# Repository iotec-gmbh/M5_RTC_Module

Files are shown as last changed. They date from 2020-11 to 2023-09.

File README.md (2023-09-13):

# M5-RTC-Module

The M5-RTC-Mod is a real time clock specifically designed for the popular ESP32 based [M5-Stack](https://m5stack.com/). It features the [RV-3028-C7 RTC from Micro Crystal](https://www.microcrystal.com/en/products/real-time-clock-rtc-modules/rv-3028-c7).

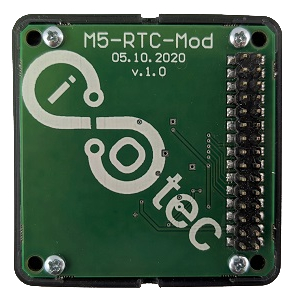
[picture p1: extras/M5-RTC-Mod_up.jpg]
M5-RTC-Module upside

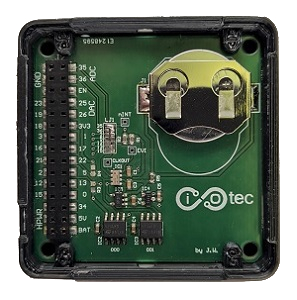
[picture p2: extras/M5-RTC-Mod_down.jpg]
M5-RTC-Module downside


## Features

+ **high precision** [RTC](https://www.microcrystal.com/en/products/real-time-clock-rtc-modules/rv-3028-c7) with ±1ppm deviation per year (±32 seconds per year)
+ extremely **long battery runtime** with a CR2032 lithium cell (at least 10 Years, considering the operating life of the battery)
+ fully compatible to the [M5Stack Core](https://m5stack.com/collections/m5-core)
+ two external [EEPROMs](https://www.st.com/en/memories/m24256-bw.html)
+ battery voltage monitoring through a 10-bit [ADC](http://ww1.microchip.com/downloads/en/DeviceDoc/20001805C.pdf).
+ configurable interrupt pin
+ 3D printable housing for an M5Stack
+ all components are connected via a single I2C bus

## Repository Contents

+ **/examples** – example sketches for the library
+ **/src** – source files for the library (`.cpp`, `.h`)
+ **/extras/hardware** – schematic, Gerber-files and bill of material
+ **/extras/3D-files** – `.stl`-file for 3D printing

## Dependencies

The library is based on the [RTC RV-3028-C7 Arduino Library](https://github.com/constiko/RV-3028_C7-Arduino_Library).
It also includes the [uEEPROMLib](https://github.com/Naguissa/uEEPROMLib) for communication with the external EEPROM via I2C.
The battery voltage is monitored using the [MCP3X21](https://github.com/pilotak/MCP3X21) library.

## API

The following functions are included in this library:

+ `begin()` – initializes the I2C-Interface and the RTC. Must be called in the setup function
+ `setLocalTimeToRTC()` – set the time on the ESP32 to the M5-RTC-Mod
+ `getBatteryStatus()` – returns true if the battery is ok, false if it's to low
+ `getBatteryVoltage()` – returns the battery Voltage in mV

This library works best in combination with functions from the included libraries:

+ Additional functions to control the **RTC** are described [here](https://github.com/constiko/RV-3028_C7-Arduino_Library#general-functions). You can use these by adding `.rtc` to the call of the function.
+ Additional functions to control the **EEPROM** are described [here](https://naguissa.github.io/uEEPROMLib_doc_and_extras/classuEEPROMLib.html). You can use these by adding `.eeprom0` or `.eeprom1` to the call of the function.
+ Additional functions to control the **ADC** are described [here](https://github.com/pilotak/MCP3X21). You can use these by adding `.adc` to the call of the function.

## Usage

Here is an example on how to use the library:

```cpp
#include <M5_RTC_Module.h>

// create an instance of the class M5_RTC_Mod
M5_RTC_Mod rtc_mod;

void setup(){
    // init RTC-Module
    rtc_mod.begin()
}

void loop(){
    // Updates the time variables from RTC
    if (rtc_mod.rtc.updateTime()) {
        currentTime = rtc_mod.rtc.stringTimeStamp();
    } else {
        // RTC failed to update
    }
}

```

### Choosing the interrupt pin

You can [set up an interrupt event](https://github.com/constiko/RV-3028_C7-Arduino_Library#alarm-interrupt-functions) on the RTC.
With the help of the solder jumper LJ1 on the M5-RTC-Mod board you can choose which IO of the ESP32 should act as an interrupt pin.

The following IOs can be chosen as an interrupt pin:

|  |  | | |  |  |  |
|--|--|-|-|--|--|--|
|35|36|2|5|12|13|15|

For example: In the following picture the IO 35 is used as an interrupt pin.

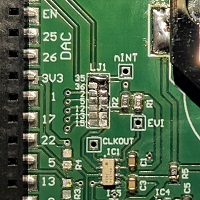
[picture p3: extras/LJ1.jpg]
LJ1


## Contribute

We look forward to contributions, reports or comments on the hardware or software.

If you have any question feel free to contact us: info@iotec-gmbh.de

## License

See [LICENSE](LICENSE) file for more information.

Copyright (c) 2020 iotec GmbH

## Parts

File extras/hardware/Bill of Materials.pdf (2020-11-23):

v.1.0 | 20.11.2020
Quantity | Comment | Designator | PartMandatory | Footprint | Description | Manufacturer | Manufacturer number
2 | 10n | C1, C3 | Yes | CAP0603_M | 10nF, at least 6.3V SMD ceramic capacitor, 0603 package | - | -
3 | 100n | C2, C4, C5 | Yes | CAP0603_M | 100nF, at least 6.3V SMD ceramic capacitor, 0603 package | - | -
1 | 1u | C6 | Yes | CAP0603_M | 1µF, at least 6.3V SMD ceramic capacitor, 0603 package | - | -
1 | RV-3028-C7 | IC1 | Yes | RV-3028-C7 | Real-Time Clock Module | Micro Chrystal | RV-3028-C7 32.768kHz 1ppm TA QC
2 | M24256 | IC2, IC3 | No | SO8N | 256-Kbit I2C-compatible EEPROM | STMicroelectronics | M24256-DFMN6TP
1 | MCP1525/41 | IC4 | No | SOT23_3L_M | 4.096V precision voltage reference | Microchip | MCP1541T-I/TT
1 | MCP3021 | IC5 | No | SOT23_5L_M | 10-bit ADC | Microchip | MCP3021A0T-E/OT
1 | CR2032-Bat-Holder | J1 | Yes | CR2032-BAT-HOLDER | SMD battery holder for CR2032 coin cell | Linx | BAT-HL-001
1 | Pin Header for the M5-Stack | J2 | Yes | 2x15 Pin Header low profile | BUS-Socket is a pair of M-BUS socket, female and male. 2X15 pins. | M5Stack | A001
4 | 10k | R1, R2, R3, R4 | Yes | RES0603_M | 10kΩ chip resistor, 0603 package | - | -
1 | 470 | R5 | Yes | RES0603_M | 470Ω chip resistor, 0603 package | - | -

Copyright (c) 2020 iotec GmbH

Bill of Material M5-RTC-Module

MIT License: Provided "as is", without warranty of any kind.

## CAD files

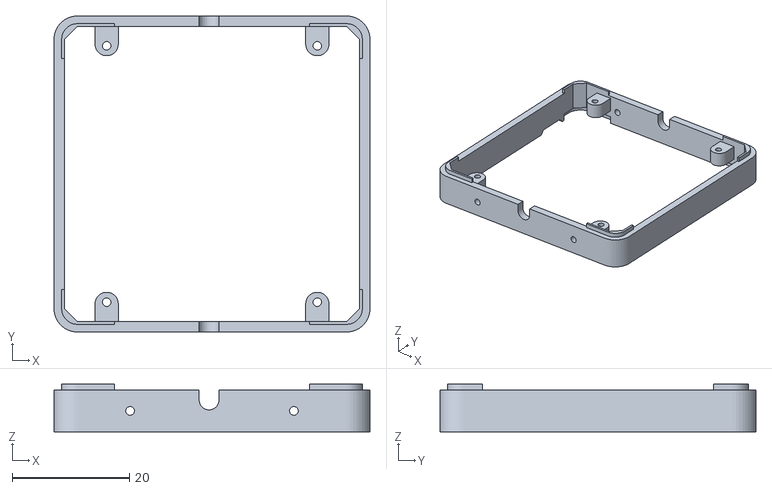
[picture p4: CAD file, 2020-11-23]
extras/3D-files/M5_RTC_Mod_Case.stl
54.0 x 54.0 x 8.15

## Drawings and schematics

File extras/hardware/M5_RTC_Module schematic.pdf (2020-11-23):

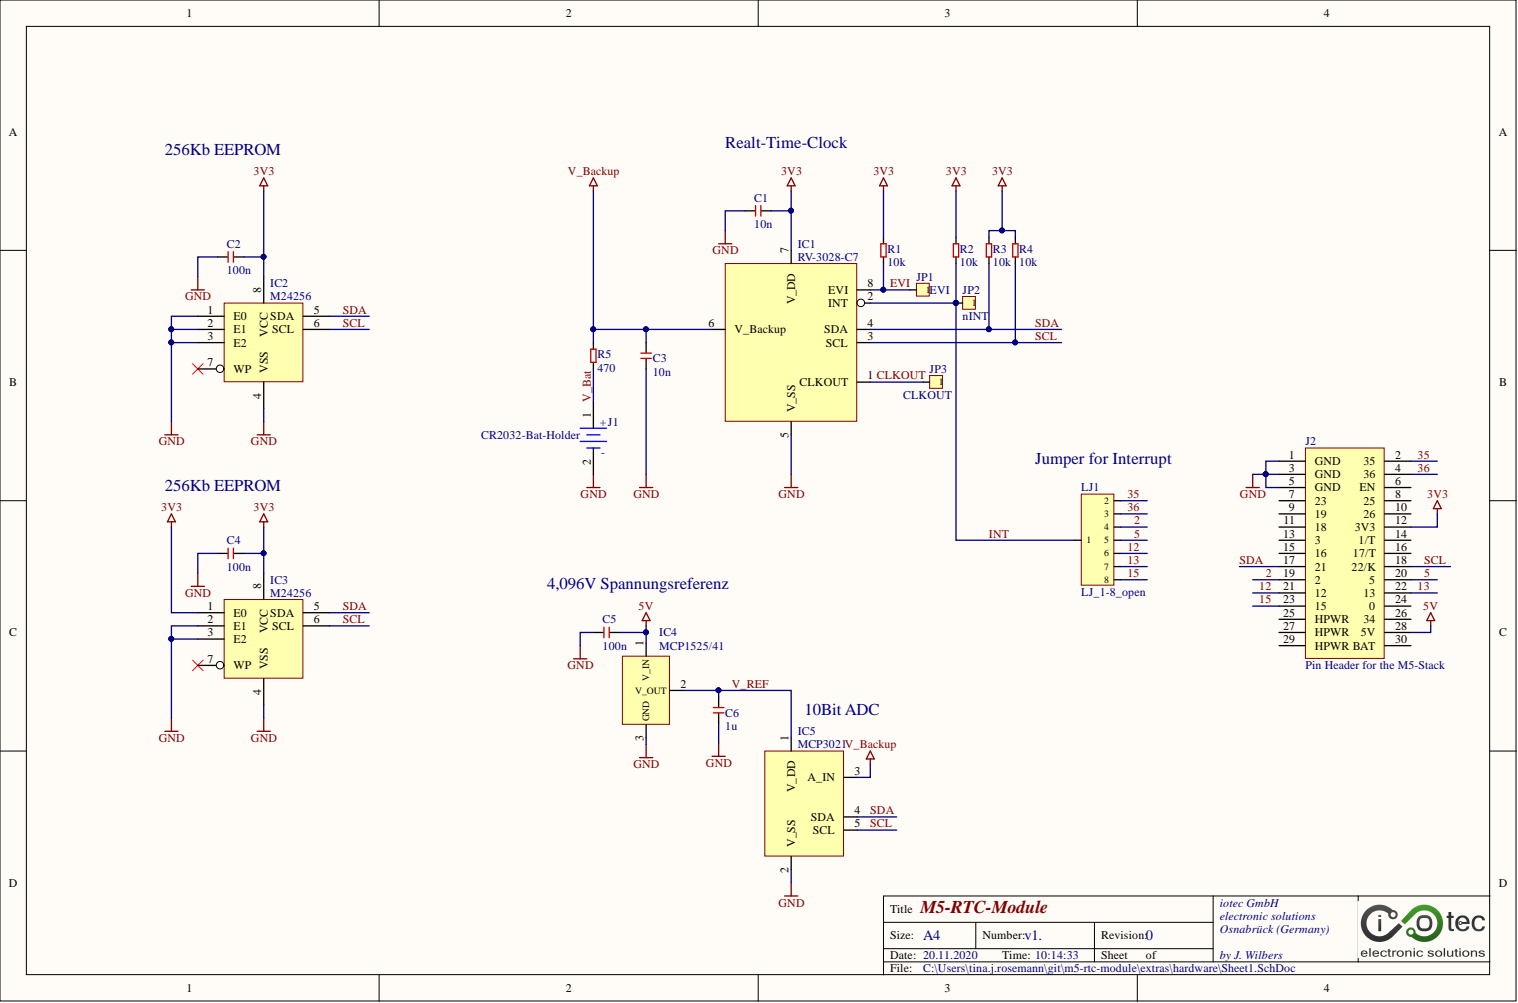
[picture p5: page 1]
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

Size: A 4 | N umber: | Rev i s i o n : 0
Date: 2 0.1 1.2 0 2 0 T ime: 1 0 : 1 4 : 3 3 | | Sheet o f

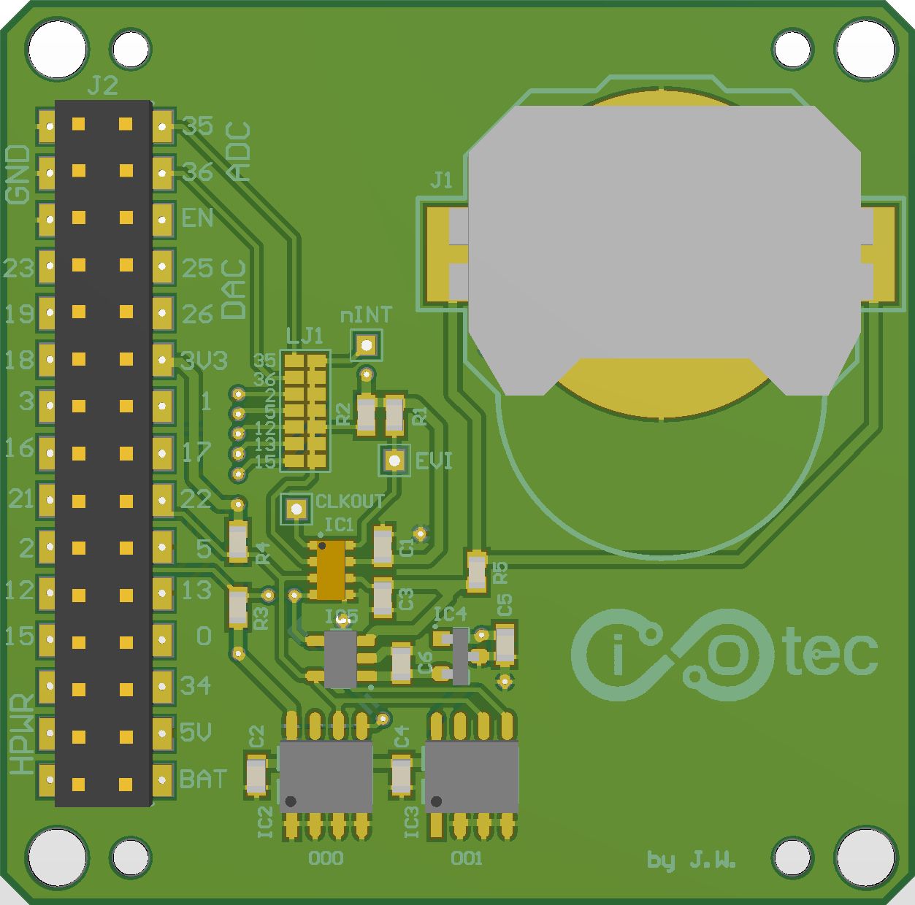
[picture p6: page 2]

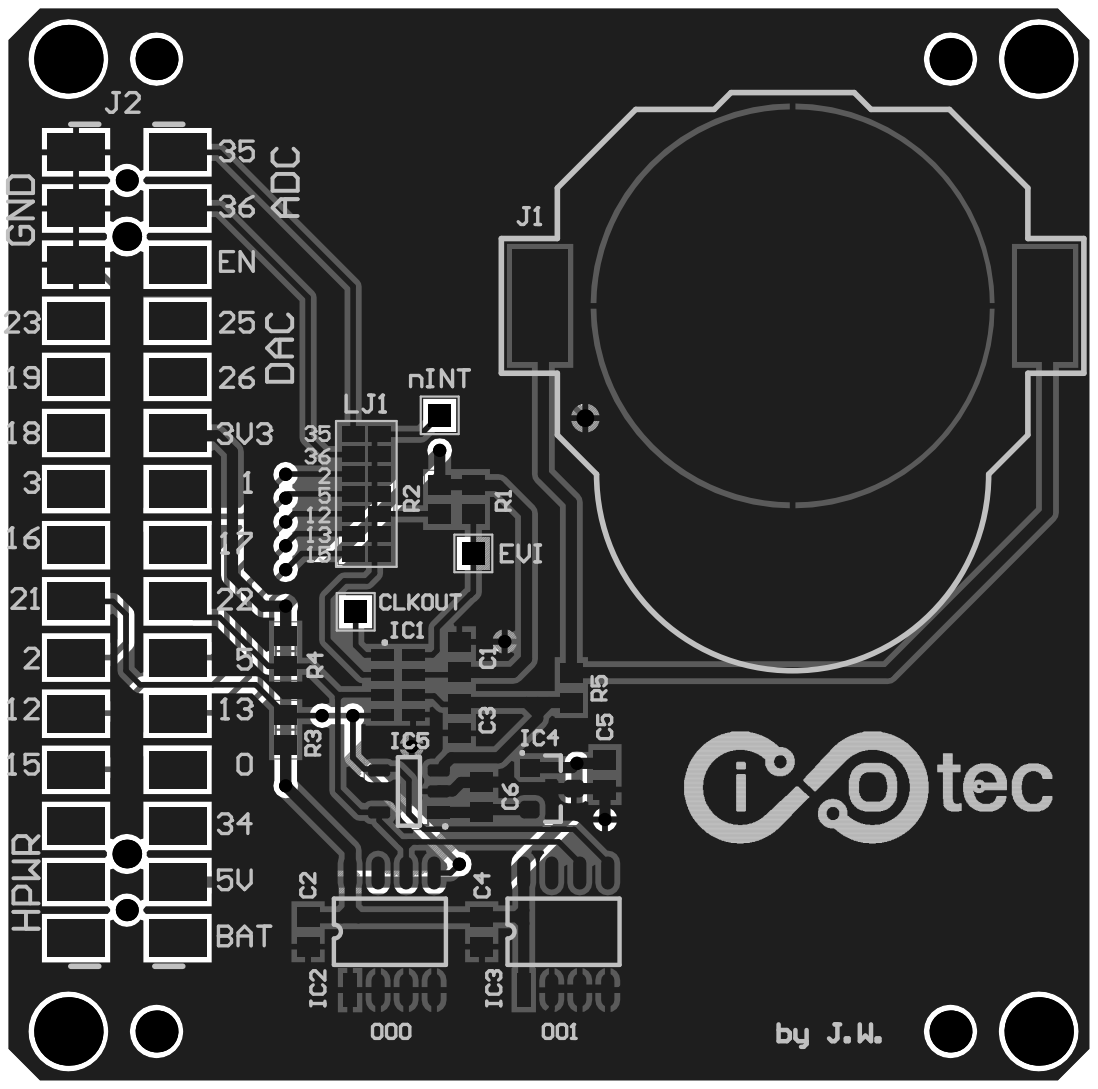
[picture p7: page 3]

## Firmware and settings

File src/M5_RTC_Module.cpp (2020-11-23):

/*
 * @file M5_RTC_Module.cpp
 * @brief Library for using the RTC-Module from iotec for the M5-Stack
 * @author Created by Johannes W.
 * @date November 12, 2020.
 * @copyright Copyright (c) 2020 iotec GmbH
 */

#include <Arduino.h>
#include <M5_RTC_Module.h>

M5_RTC_Mod::M5_RTC_Mod(uint8_t adrEeprom0, uint8_t adrEeprom1, uint8_t adrAdc)
    : eeprom0(adrEeprom0),
      eeprom1(adrEeprom1),
      rtc(),
      adc(adrAdc) {
}

bool M5_RTC_Mod::begin(TwoWire &wirePort, bool set24Hour, bool disableTrickleCharge, bool setLevelSwitchingMode) {
    // initialize I2C communication
    wirePort.begin();

    // initialize adc
    adc.init(&wirePort);

    // initialize real time clock
    if (rtc.begin(wirePort, set24Hour, disableTrickleCharge, setLevelSwitchingMode)) {
        return true;
    } else {
        return false;
    }

    // set all values in the rtc to default and clear all flags
    rtc.clearInterrupts();
    rtc.disableAlarmInterrupt();
    rtc.clearAlarmInterruptFlag();
    rtc.disableTimer();
    rtc.disableTimerInterrupt();
    rtc.clearTimerInterruptFlag();
    rtc.disablePeriodicUpdateInterrupt();
    rtc.clearPeriodicUpdateInterruptFlag();
    rtc.disableClockOut();
    rtc.clearClockOutputInterruptFlag();
    rtc.reset();

    // write system time to RTC
    setLocalTimeToRTC();
}

// write time to RTC
bool M5_RTC_Mod::setLocalTimeToRTC() {
    // store time struct
    struct tm timeinfo;
    // read system time
    if (!getLocalTime(&timeinfo)) {
        return false;
    }
    // set time to rtc
    if (rtc.setTime(timeinfo.tm_sec, timeinfo.tm_min, timeinfo.tm_hour, timeinfo.tm_wday,
                    timeinfo.tm_mday, timeinfo.tm_mon + 1, timeinfo.tm_year + 1900) == false) {
        return false;
    }
    return true;
}

uint16_t M5_RTC_Mod::getBatteryVoltage() {
    // get value from adc
    _valueADC = adc.read();
    // return calculated voltage in mV
    return adc.toVoltage(_valueADC, REF_VOLTAGE);
}

bool M5_RTC_Mod::getBatteryStatus() {
    // get voltage from adc
    if (getBatteryVoltage() > 2500) {
        // battery voltage ok
        return true;
    } else {
        // battery voltage too low
        return false;
    }
}

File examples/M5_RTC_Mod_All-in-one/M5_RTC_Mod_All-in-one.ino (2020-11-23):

/*
 * In this sketch the RTC is synchronized witch an NTP-server.
 * Once in an hour the voltage of the battery is read out.
 * The values are stored in the EEPROM together with a timestamp.
 * If the battery of the RTC is to low a message is printed
 * and the program will loop until restart.
 */

#include <M5Stack.h>
#include <WiFi.h>
#include <time.h>

#include "M5_RTC_Module.h"

const char *SSID = "YOUR_SSID";
const char *PASSWORD = "YOUR_PASS";

// select your local NTP server from this site: https://www.ntppool.org/zone/@
const char *NTP_SERVER = "pool.ntp.org";
// select your timezone from this list: https://github.com/nayarsystems/posix_tz_db/blob/master/zones.csv
const char *TIME_ZONE = "CET-1CEST,M3.5.0/02,M10.5.0/03";

// The below variables control what the alarm will be set to
const uint8_t ALM_MINUTE = 12;
const uint8_t ALM_HOUR = 10;
const uint16_t ALM_DATE_OR_WEEKDAY = 2;
const bool ALM_IS_WEEKDAY = false;
// Alarm when minutes match
// More informations can be found here: https://github.com/constiko/RV-3028_C7-Arduino_Library
const uint8_t ALM_MODE = 6;

// Create M5_RTC_Mod instance
M5_RTC_Mod rtc_mod;

// position where to write in EEPROM
unsigned int pos;

void setup() {
    // Initialize the M5Stack object
    M5.begin();
    // clear screen
    M5.Lcd.fillScreen(BLACK);
    // set white text color with black background
    M5.Lcd.setTextColor(WHITE, BLACK);
    // set text size
    M5.Lcd.setTextSize(2);
    // print example name
    M5.Lcd.drawCentreString(" M5-RTC-Mod_All-in-one ", 320 / 2, 0, 2);
    M5.Lcd.setCursor(0, 30);

    // init M5-RTC-Module
    if (rtc_mod.begin()) {
        M5.Lcd.println("M5-RTC-Mod online");
    } else {
        M5.Lcd.println("Can't connect to M5-RTC-Mod");
        // if communication failed, loop here forever
        while (1)
            ;
    }

    // connect to WiFi
    M5.Lcd.setTextSize(1);
    M5.Lcd.printf("Connecting to %s ", SSID);
    WiFi.begin(SSID, PASSWORD);
    while (WiFi.status() != WL_CONNECTED) {
        delay(500);
        M5.Lcd.print(".");
    }
    M5.Lcd.println(" CONNECTED");

    // init and get the local time
    configTzTime(TIME_ZONE, NTP_SERVER);

    // write time to RTC
    M5.Lcd.setTextSize(2);
    if (rtc_mod.setLocalTimeToRTC()) {
        // RTC set correctly, print it's time
        M5.Lcd.printf("Time: %02d:%02d\n", rtc_mod.rtc.getHours(), rtc_mod.rtc.getMinutes());
        M5.Lcd.printf("Date: %02d.%02d.%d\n", rtc_mod.rtc.getDate(), rtc_mod.rtc.getMonth(), rtc_mod.rtc.getYear());
    } else {
        M5.Lcd.println("Something went wrong setting the time");
    }

    // disconnect WiFi as it's no longer needed
    WiFi.disconnect(true);
    WiFi.mode(WIFI_OFF);

    // Enable alarm interrupt
    rtc_mod.rtc.enableAlarmInterrupt(ALM_MINUTE, ALM_HOUR, ALM_DATE_OR_WEEKDAY, ALM_IS_WEEKDAY, ALM_MODE);
    // Only disables the interrupt (not the alarm flag)
    rtc_mod.rtc.disableAlarmInterrupt();

    // display current configuration
    M5.Lcd.setTextSize(1);
    switch (ALM_MODE) {
        case 0:
            M5.Lcd.println("Interrupt occurs when minutes, hours and weekday/date match");
            break;
        case 1:
            M5.Lcd.println("Interrupt occurs when hours and weekday/date match (once per weekday/date)");
            break;
        case 2:
            M5.Lcd.println("Interrupt occurs when minutes and weekday/date match (once per hour per weekday/date)");
            break;
        case 3:
            M5.Lcd.println("Interrupt occurs when weekday/date match (once per weekday/date)");
            break;
        case 4:
            M5.Lcd.println("Interrupt occurs when hours and minutes match (once per day)");
            break;
        case 5:
            M5.Lcd.println("Interrupt occurs when hours match (once per day)");
            break;
        case 6:
            M5.Lcd.println("Interrupt occurs when minutes match (once per hour)");
            break;
        case 7:
            M5.Lcd.println("Interrupts are all disabled – default value");
            break;
        default:
            break;
    }

    M5.Lcd.printf("Alarm set to: %02d:%02d \n", ALM_HOUR, ALM_MINUTE);

    M5.Lcd.printf("date or weekday: %d\n", ALM_DATE_OR_WEEKDAY);
    M5.Lcd.printf("weekday alarm: %d \n", ALM_IS_WEEKDAY);

    M5.Lcd.setTextSize(2);
    M5.Lcd.println("waiting for next alarm");
}

void loop() {
    // check if RTC battery is ok
    if (rtc_mod.getBatteryStatus()) {
        // String where the time is stored
        String currentTime = " ";

        // Updates the time variables from RTC
        if (rtc_mod.rtc.updateTime()) {
            currentTime = rtc_mod.rtc.stringTimeStamp();
        } else {
            M5.Lcd.print("RTC failed to update");
        }

        // poll alarm interrupt flag
        if (rtc_mod.rtc.readAlarmInterruptFlag()) {
            // read adc value
            uint16_t valueADC = rtc_mod.adc.read();
            // calculate voltage
            float volt = rtc_mod.adc.toVoltage(valueADC, rtc_mod.REF_VOLTAGE) / 1000.0;
            // parse float to string
            String voltStr = String(volt);

            // merge voltage and timestamp in one string
            String timestamp = voltStr + "V " + currentTime;
            // save string in char array to write into eeprom
            char timestampChar[timestamp.length() + 1] = {0};
            timestamp.toCharArray(timestampChar, sizeof(timestampChar));

            // write the char array into eeprom
            if (!rtc_mod.eeprom0.eeprom_write(pos, (byte *)timestampChar, sizeof(timestampChar))) {
                M5.Lcd.println("Failed to store timestamp in EEPROM");
            } else {
                M5.Lcd.println("The timestamp has been stored in EEPROM.");
            }

            // read eeprom to verrify data
            char storedTimestamp[sizeof(timestampChar)] = {0};
            rtc_mod.eeprom0.eeprom_read(pos, (byte *)storedTimestamp, sizeof(storedTimestamp));

            M5.Lcd.println(storedTimestamp);

            // set new writing position of eeprom
            pos += sizeof(timestampChar);

            // clear RTC interrupt flag
            rtc_mod.rtc.clearAlarmInterruptFlag();

            M5.Lcd.println("waiting for next alarm");
        }
    } else {
        // Battery is empty. Print a message with the current voltage
        M5.Lcd.printf("LOW BATTERY: %.2fV \n", rtc_mod.getBatteryVoltage() / 1000.0);
        // loop here forever
        while (1)
            ;
    }

    // refresh display
    M5.update();

    delay(1000);
}
